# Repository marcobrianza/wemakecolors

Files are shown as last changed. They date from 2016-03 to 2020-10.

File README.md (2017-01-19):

“We Make Colors” is a network of artworks that dynamically generate random colors based on a physical presence near each device.
All copies of the artwork generate and broadcast to each other the new colors in real time using MQTT, current standard protocol for IoT.
The artworks create an unintentional interaction between the spaces and persons. The colors scroll in the device like in a social network timeline: new colors enter from the top and old ones exit from the bottom. All the devices have the same colors at the same time.

The colors of each device are produced by a strip of 9 RGB addressable LEDs.
The new color is generated when the passive infrared sensor interrupts the microprocessor count loop, typically when a human is passing by. There is no identification of the device that generates the new color.
To avoid information flooding and an intentional interaction, the maximum color frequency is one per minute per each device.
The processor is based on the Wi-Fi SoC ESP8266 programmed with the Arduino IDE. The device is open source and can be made with a 60×30 cm laser cutter, available in every Fablab. The main construction element is a 3 mm acrylic sheet. The bill of the material is below 20 €, including a 3 $ donation to Arduino.cc for the IDE support.

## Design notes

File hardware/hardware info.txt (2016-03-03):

board
https://github.com/nodemcu/nodemcu-devkit-v1.0

serial usb drivers
https://www.silabs.com/products/mcu/Pages/USBtoUARTBridgeVCPDrivers.aspx

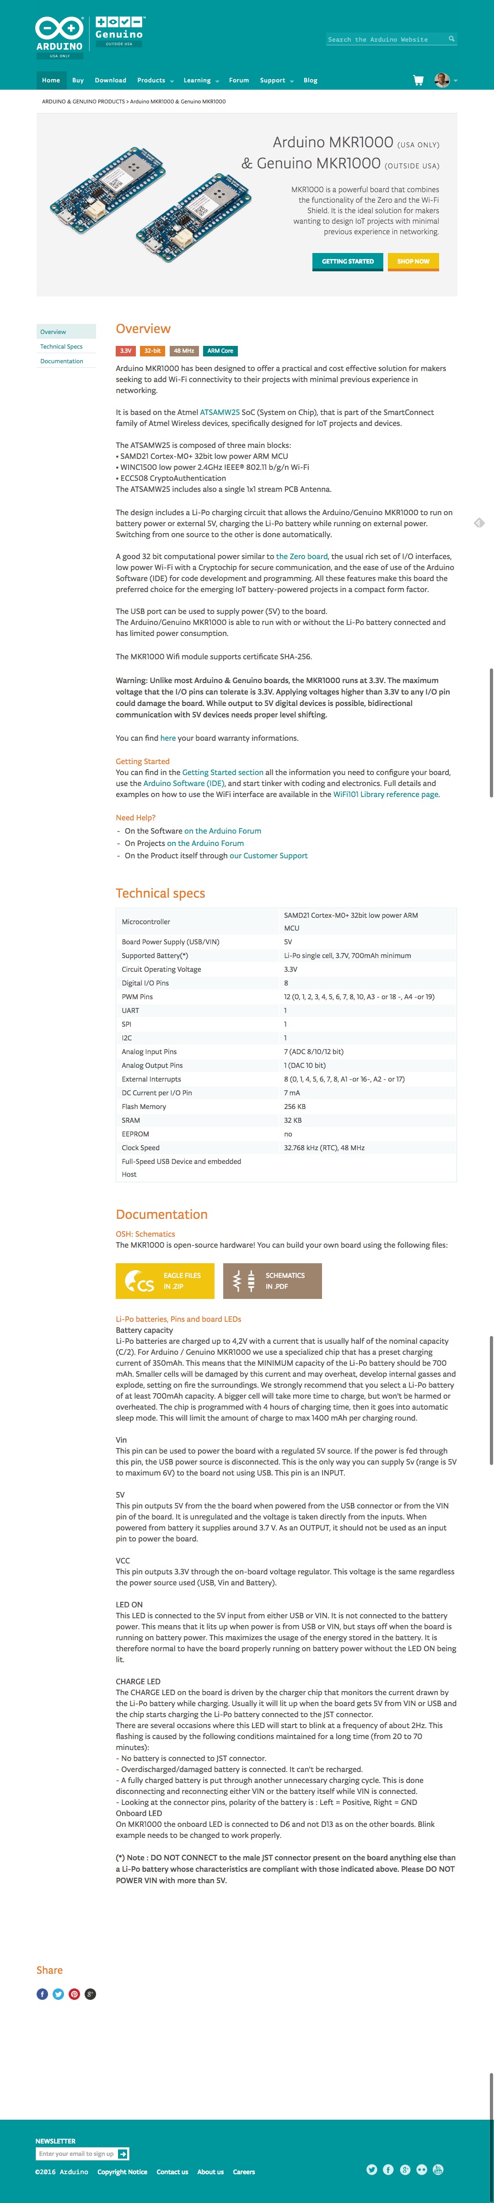
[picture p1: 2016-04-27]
hardware/MKR1000-page.jpg

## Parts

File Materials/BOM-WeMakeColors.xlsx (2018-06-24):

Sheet: bom 1.1
WeMakeColors Bill of materials
 | Product code | Details | Pieces lot | Price lot | Price Piece | Parts | Price parts | Origin | Shipping cost | Price category | Link
Plexiglass white 3mm | WN297 GT | 1050x820 | 6 | 35.63 | 5.938 | 1 | 5.94 | DE | 15 |  | https://www.plexiglas-shop.com/IT/it/xt-allround-8ny276huqre/plexiglas-xt-allround-bianco-wn297-gt-cfy07wjb25z~p.html
Plexiglass white 1mm | 99532 GT | 420x297 | 7 | 8.00 | 1.143 | 1 | 1.14 | DE |  | 7.08 | https://www.plexiglas-shop.com/IT/it/foglio-7amim86q5ps/plexiglas-foglio-bianco-99532-gt-1-0-mm-iqq6a1wurpd~p.html
LED strip 9 LED | White 5 m 30 IP30 | WS2812B | 150 | 16.10 | 0.107 | 9 | 0.97 | CN | 0 |  | http://it.aliexpress.com/item/1m-4m-5m-WS2812B-Smart-led-pixel-strip-Black-White-PCB-30-60-144-leds-m/2036819167.html
ESP8266 | NodeMCU 1.0 |  |  |  | 3.160 | 1 | 3.16 | CN | 0 |  | http://it.aliexpress.com/item/New-Wireless-module-NodeMcu-Lua-WIFI-Internet-of-Things-development-board-based-ESP8266-with-pcb-Antenna/32299982691.html
PIR Sensor | HC-SR501 |  | 5 | 3.88 | 0.776 | 1 | 0.78 | CN | 0 |  | http://it.aliexpress.com/item/Free-Shipping-5PCS-HC-SR501-Adjust-IR-Pyroelectric-Infrared-PIR-module-Motion-Sensor-Detector-Module/1766530570.html
connecting wires | 20 cm |  | 400 | 10.02 | 0.025 | 3 | 0.08 | CN | 0 |  | http://it.aliexpress.com/item/Free-Shipping-400pcs-dupont-cable-jumper-wire-dupont-line-female-to-female-dupont-line-20cm-1P/1727878715.html
connecting wires | 10 cm |  | 40 | 0.64 | 0.016 | 1 | 0.02 | CN | 0 |  | http://it.aliexpress.com/item/40pcs-lot-10cm-2-54mm-1pin-feMale-to-feMale-jumper-wire-Dupont-cable/32226515120.html
USB Cable | White 3m flat |  | 10 | 10.47 | 1.047 | 1 | 1.05 | CN | 0 |  | http://it.aliexpress.com/item/Fedex-shipping-100pcs-lot-3M-Noodle-flat-color-USB-Micro-cable-for-HTC-Samsung-Galaxy-S3/1472726264.html
USB Power supply 1A | a1400 clone |  | 10 | 13 | 1.300 | 1 | 1.30 | CN | 0 | 7.34 | http://it.aliexpress.com/item/10Pcs-lot-Original-Quality-5V-1A-A1400-White-Flat-EU-AC-USB-Wall-Charger-Travel-Adapter/32624571534.html
screw 2x25 | B2X25/BN330 |  |  |  | 0.026 | 10 | 0.26 | PL | 7.9 |  | http://www.tme.eu/it/details/b2x25_bn330/bulloni/bossard/1122886/
screw 2x10 | B2X10/BN341 |  |  |  | 0.013 | 2 | 0.03 | PL |  |  | http://www.tme.eu/it/details/b2x10_bn341/bulloni/bossard/1127799/
screw 2x6 | B2X6/BN341 |  |  |  | 0.019 | 2 | 0.04 | PL |  |  | http://www.tme.eu/it/details/b2x6_bn341/bulloni/bossard/1127772/
spacer 2x15 | TFM-M2X15/DR221 |  |  |  | 0.111 | 2 | 0.22 | PL |  |  | http://www.tme.eu/it/details/tfm-m2x15_dr221/distanziali-in-metallo/dremec/221x15/
bolt 2ma | B2/BN628 |  |  |  | 0.013 | 20 | 0.25 | PL |  | 0.80 | http://www.tme.eu/it/details/b2_bn628/dadi/bossard/m2bn628/
Arduino donation |  |  |  |  | 2.700 | 1 | 2.7 | (NA) |  |  | https://www.arduino.cc/en/Main/Donate
 |  |  |  |  |  | TOTAL € | 17.92 |  |  | 15.22

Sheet: alternatives
WeMake Colors Bill of materials
 | Product code | Details | Pieces lot | Price lot | Price Piece | Parts | Price parts | Origin | Shipping cost | Price cathegory | Link
USB Power supply 1A | AK-CH-03W |  |  |  | 2.2800 | 1 | 2.28 | PL | 7.9 | 2.28 | http://www.tme.eu/it/details/ak-ch-03w/alimentatori-a-presa-di-corrente/akyga/ccabkeyaky-07309/
USB Cable | White 3M flat |  | 10 | 10.47 | 1.0470 | 1 | 1.05 | CN | 0 |  | http://it.aliexpress.com/item/Fedex-shipping-100pcs-lot-3M-Noodle-flat-color-USB-Micro-cable-for-HTC-Samsung-Galaxy-S3/1472726264.html
spacer 2x15 | FIX-TP2-15 | plastic discontinued

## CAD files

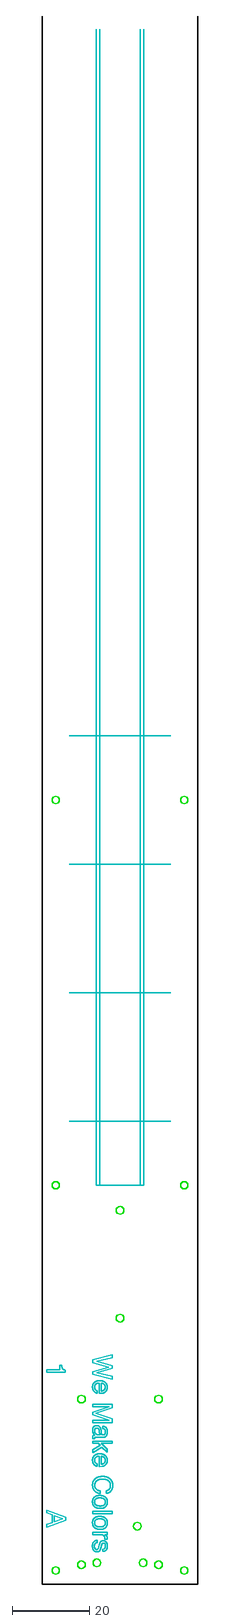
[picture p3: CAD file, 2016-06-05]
design/production/wmc_1A_bottom.dxf
40.3 x 407.0

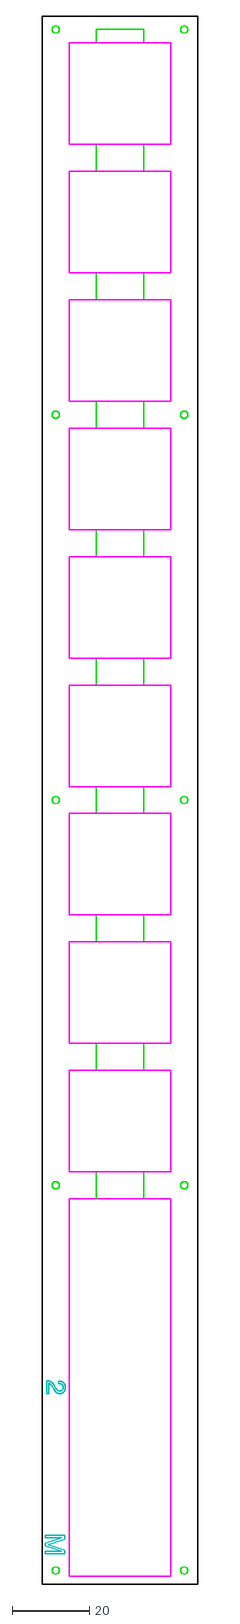
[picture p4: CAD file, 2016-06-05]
design/production/wmc_2M_cuts.dxf
40.3 x 407.0

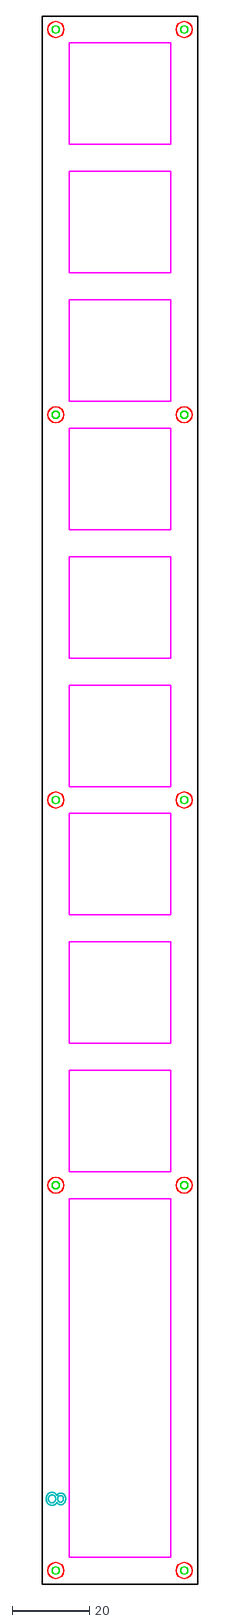
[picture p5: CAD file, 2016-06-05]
design/production/wmc_8_engrave.dxf
40.3 x 407.0

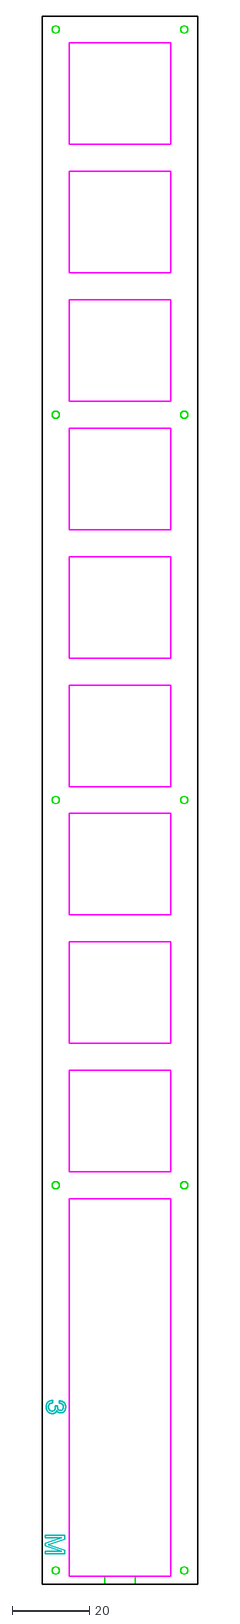
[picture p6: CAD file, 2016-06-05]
design/production/wmc_3M.dxf
40.3 x 407.0

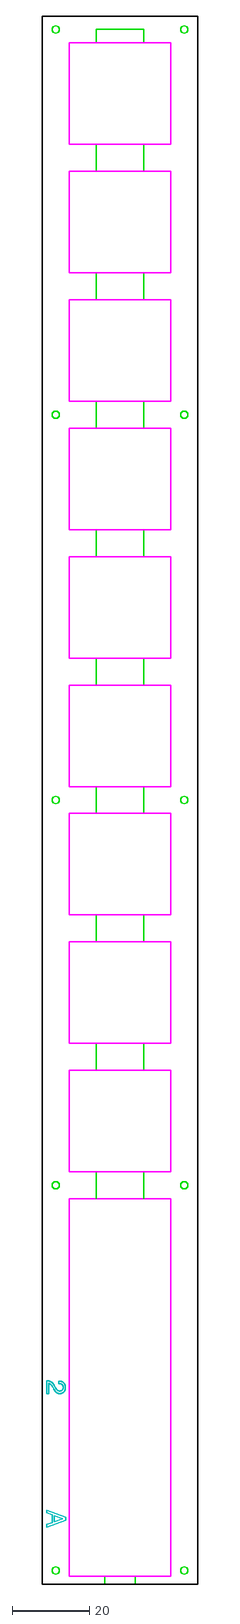
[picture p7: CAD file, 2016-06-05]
design/production/wmc_2A_cuts.dxf
40.3 x 407.0

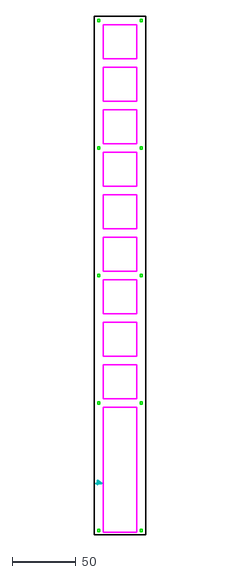
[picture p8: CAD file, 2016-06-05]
design/production/wmc_4.dxf
40.3 x 407.0

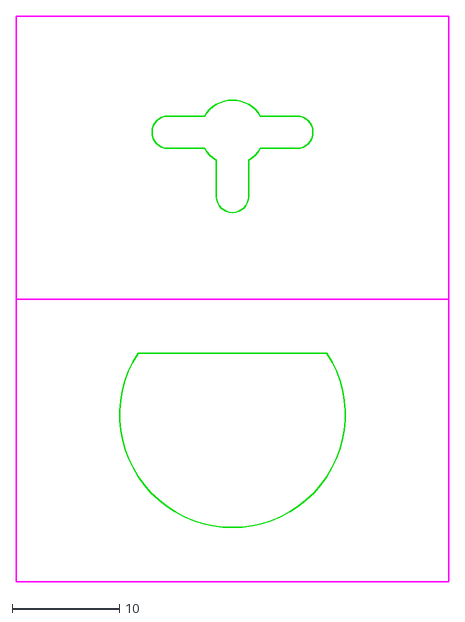
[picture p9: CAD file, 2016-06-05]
design/production/wmc_10_fixing.dxf
40.3 x 52.7

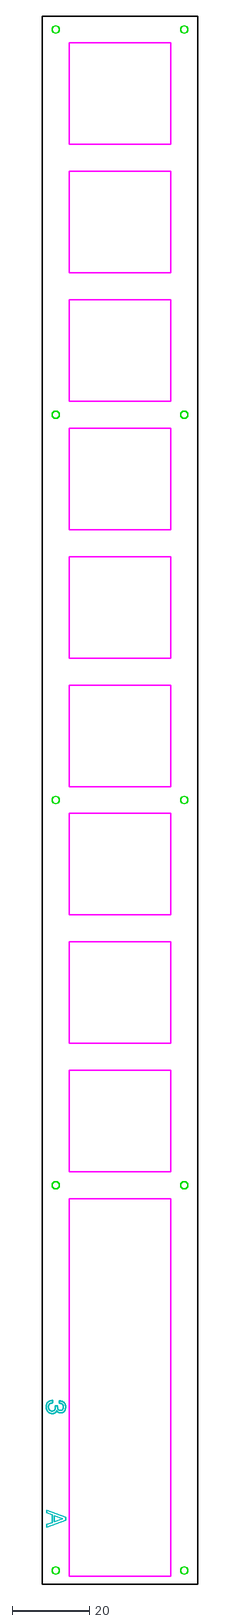
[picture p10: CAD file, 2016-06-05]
design/production/wmc_3A.dxf
40.3 x 407.0

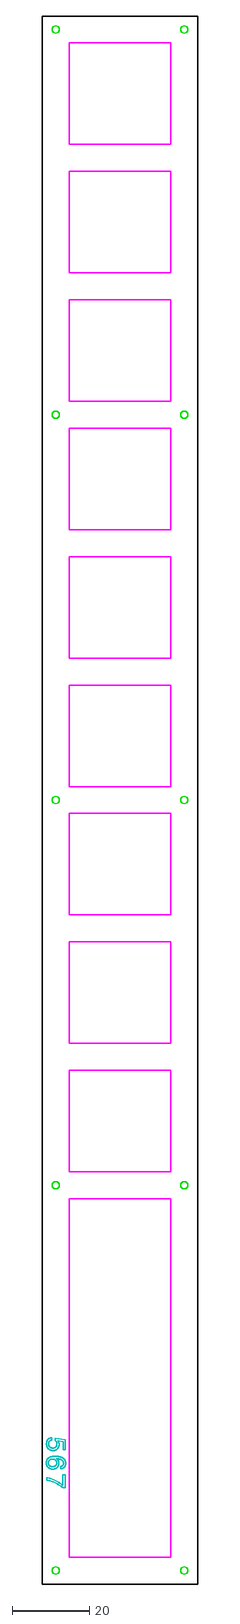
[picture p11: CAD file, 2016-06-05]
design/production/wmc_5-6-7.dxf
40.3 x 407.0

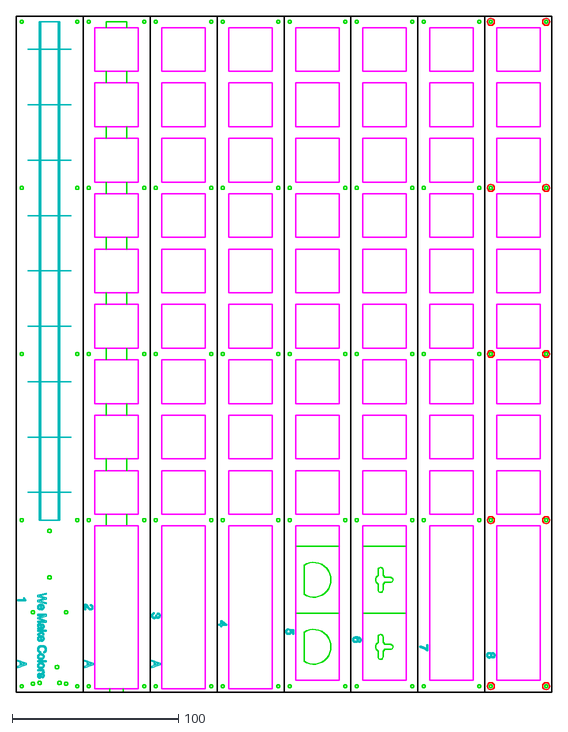
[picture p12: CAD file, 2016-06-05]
design/production/wmc_production_1.1A.dxf
322.6 x 407.0

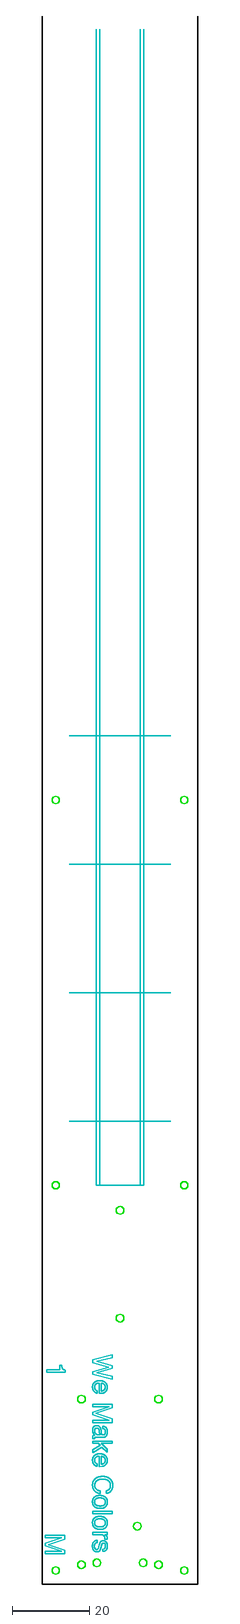
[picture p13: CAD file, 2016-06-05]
design/production/wmc_1M_bottom.dxf
40.3 x 407.0

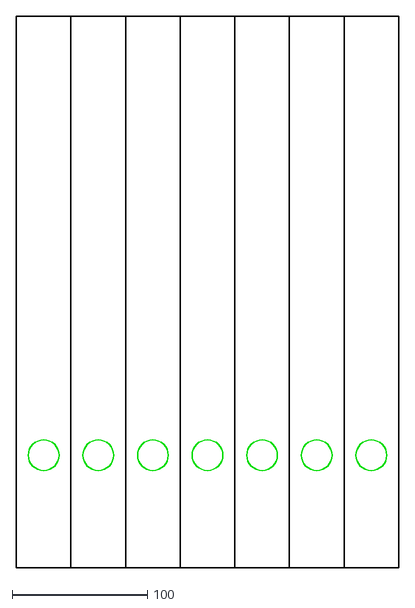
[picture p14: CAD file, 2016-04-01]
design/production/wmc_production_7diffusers.dxf
282.3 x 407.0

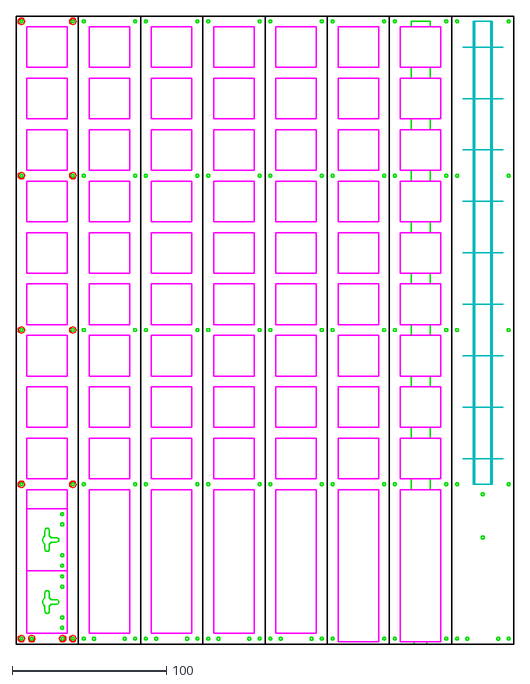
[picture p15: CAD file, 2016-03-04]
design/production/WeMakeColors-production-8.dxf
322.6 x 407.0

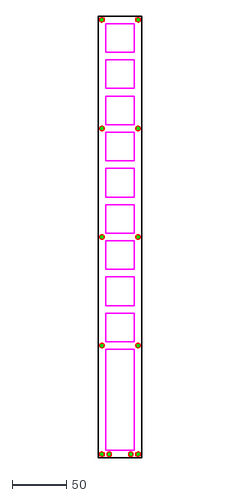
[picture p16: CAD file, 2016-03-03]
design/production/1-engrave.dxf
40.3 x 407.0

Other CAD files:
design/production/wmc_9_diffuser.dxf
design/production/8-bottom.dxf
design/WeMakeColors_1.0.3dm
design/WeMakeColors_1.1.3dm
design/WeMakeColors_production-7diffusers.3dm
design/WeMakeColors_production_1.0.3dm
design/wmc_production_1.1A.3dm

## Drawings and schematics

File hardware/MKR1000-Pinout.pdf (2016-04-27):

# MKR1000 PINOUT

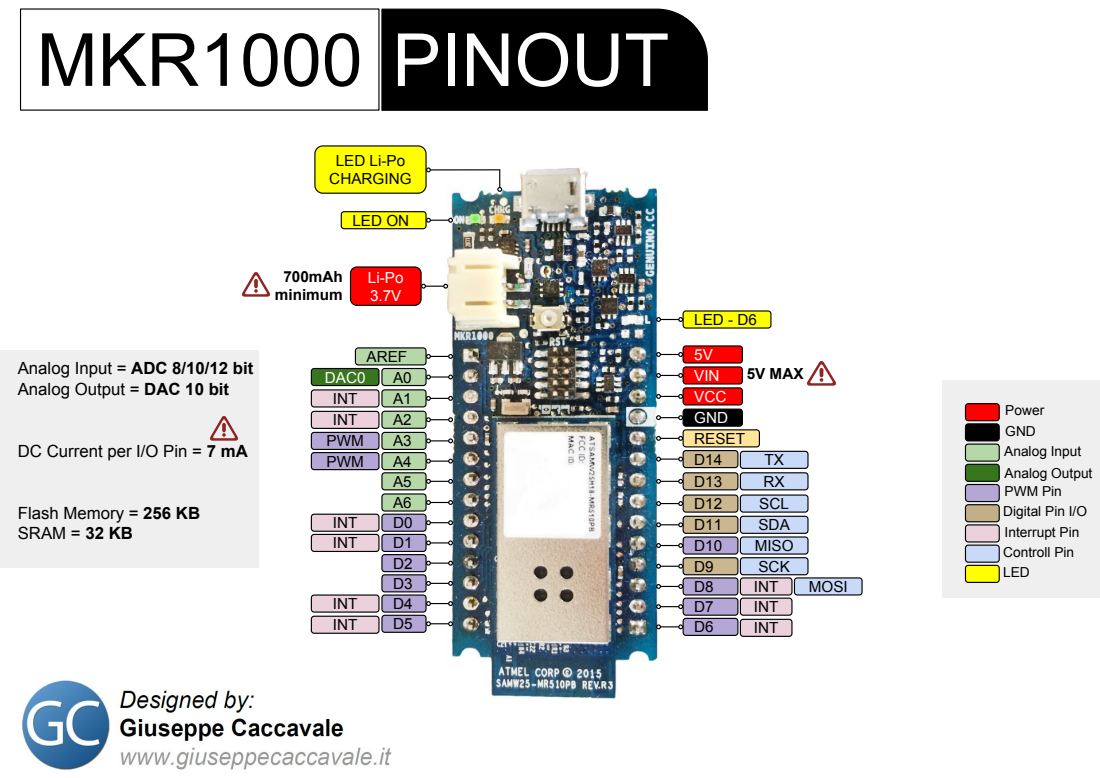
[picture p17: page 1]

Analog Input = ADC 8/10/12 bit
Analog Output = DAC 10 bit

DC Current per I/O Pin = 7 mA

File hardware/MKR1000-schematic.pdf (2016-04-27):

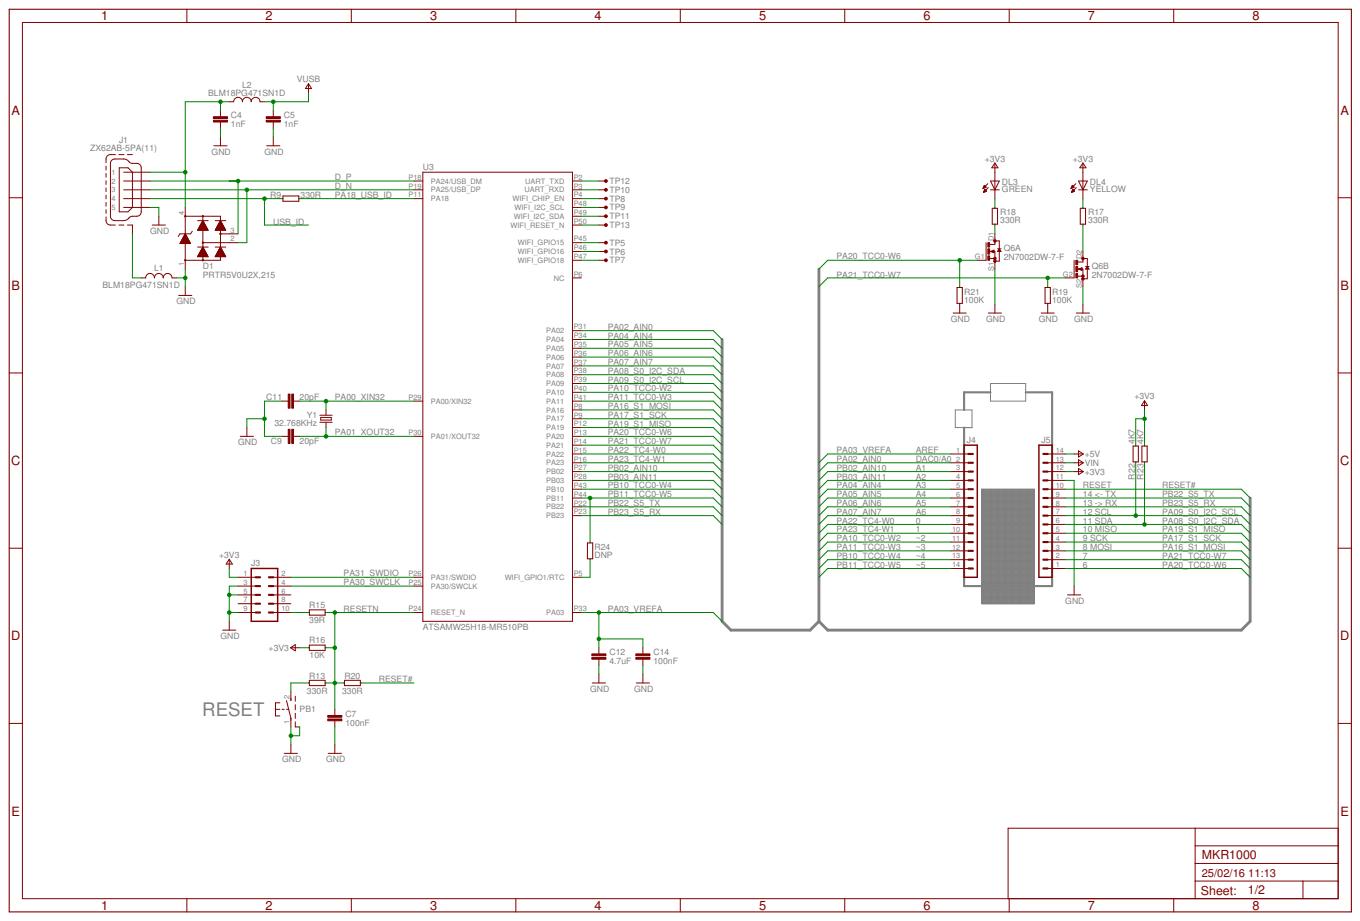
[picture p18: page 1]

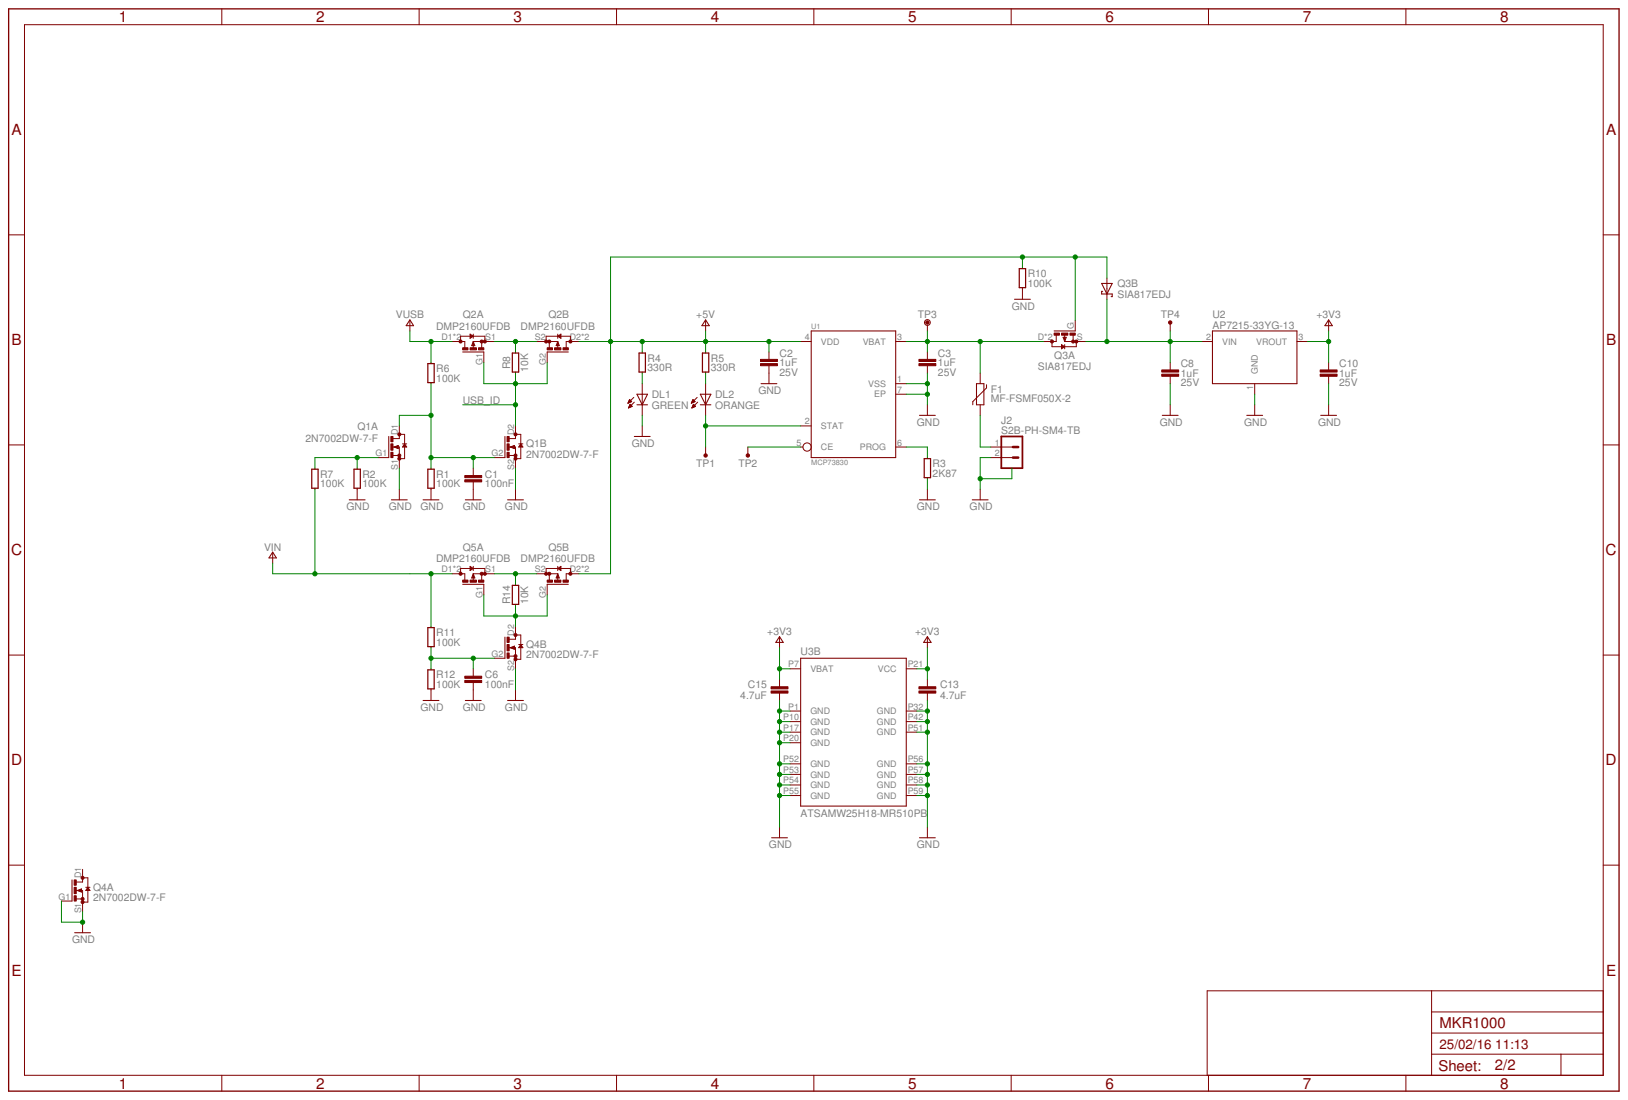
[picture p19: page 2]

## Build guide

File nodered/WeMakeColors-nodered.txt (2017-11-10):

[
    {
        "id": "24e2fff5.8e31e",
        "type": "tab",
        "label": "WeMakeColors"
    },
    {
        "id": "9dfacebf.88269",
        "type": "inject",
        "z": "24e2fff5.8e31e",
        "name": "",
        "topic": "",
        "payload": "true",
        "payloadType": "bool",
        "repeat": "",
        "crontab": "",
        "once": false,
        "x": 122.5,
        "y": 215,
        "wires": [
            [
                "91c1f08a.cf3a4"
            ]
        ]
    },
    {
        "id": "91c1f08a.cf3a4",
        "type": "function",
        "z": "24e2fff5.8e31e",
        "name": "random color",
        "func": "\nvar array = new Uint8Array(3);\n\narray[0] = Math.random() * 15;\narray[1] = Math.random() * 15;\narray[2] = Math.random() * 15;\n\n\nbu=new Buffer(array)\nvar newMsg = { payload: bu };\n\nreturn newMsg;\n",
        "outputs": 1,
        "noerr": 0,
        "x": 319.5,
        "y": 220,
        "wires": [
            [
                "bfa1409d.0ca74"
            ]
        ]
    },
    {
        "id": "bfa1409d.0ca74",
        "type": "mqtt out",
        "z": "24e2fff5.8e31e",
        "name": "",
        "topic": "/WeMakeColors/color",
        "qos": "",
        "retain": "",
        "broker": "7311599b.6bd6b8",
        "x": 564.5,
        "y": 220,
        "wires": []
    },
    {
        "id": "560c032e.b9441c",
        "type": "mqtt in",
        "z": "24e2fff5.8e31e",
        "name": "",
        "topic": "/WeMakeColors/color",
        "qos": "2",
        "broker": "7311599b.6bd6b8",
        "x": 150.5,
        "y": 470,
        "wires": [
            [
                "8875bbff.1bd1c8"
            ]
        ]
    },
    {
        "id": "5ffecd45.d60de4",
        "type": "ui_button",
        "z": "24e2fff5.8e31e",
        "name": "",
        "group": "d0b4d42e.7a7688",
        "order": 0,
        "width": 0,
        "height": 0,
        "passthru": false,
        "label": "Random Color",
        "color": "",
        "bgcolor": "",
        "icon": "",
        "payload": "true",
        "payloadType": "bool",
        "topic": "",
        "x": 119.5,
        "y": 298,
        "wires": [
            [
                "91c1f08a.cf3a4"
            ]
        ]
    },
    {
        "id": "8875bbff.1bd1c8",
        "type": "function",
        "z": "24e2fff5.8e31e",
        "name": "decode color",
        "func": "node.log(\"new message\")\n\nvar array = new Uint8Array(3);\narray=msg.payload;\n\n//var r=msg.payload.buffer[0];\n//var g=msg.payload.buffer[1];\n//var b=msg.payload.buffer[2];\nvar r=array[0];\nvar g=array[1];\nvar b=array[2];\n\nnode.log(r);\nnode.log(g);\nnode.log(b);\n\nmsg.Background=\"#00FF00\";\n\nreturn msg;",
        "outputs": 1,
        "noerr": 0,
        "x": 388.5,
        "y": 470,
        "wires": [
            []
        ]
    },
    {
        "id": "e8f3ede5.8d67",
        "type": "debug",
        "z": "24e2fff5.8e31e",
        "name": "",
        "active": true,
        "console": "false",
        "complete": "payload",
        "x": 450.5,
        "y": 108,
        "wires": []
    },
    {
        "id": "502f2e90.4af54",
        "type": "ui_colour_picker",
        "z": "24e2fff5.8e31e",
        "name": "",
        "label": "",
        "group": "d0b4d42e.7a7688",
        "format": "rgb",
        "outformat": "object",
        "showSwatch": true,
        "showPicker": false,
        "showValue": false,
        "showAlpha": false,
        "showLightness": true,
        "order": 0,
        "width": 0,
        "height": 0,
        "passthru": true,
        "topic": "",
        "x": 123.5,
        "y": 368,
        "wires": [
            [
                "441228de.7ac208"
            ]
        ]
    },
    {
        "id": "441228de.7ac208",
        "type": "function",
        "z": "24e2fff5.8e31e",
        "name": "pick color",
        "func": "\nvar array = new Uint8Array(3);\n\nvar r = msg.payload.r;\nvar g = msg.payload.g;\nvar b = msg.payload.b;\n\narray[0]=r/16;\narray[1]=g/16;\narray[2]=b/16;\n\nnode.log(\"colore\",r,g,b);\n\nbu=new Buffer(array)\nvar newMsg = { payload: bu };\n\nreturn newMsg;",
        "outputs": 1,
        "noerr": 0,
        "x": 345.5,
        "y": 367,
        "wires": [
            [
                "bfa1409d.0ca74"
            ]
        ]
    },
    {
        "id": "12607667.8dd77a",
        "type": "mosca in",
        "z": "24e2fff5.8e31e",
        "mqtt_port": 1883,
        "mqtt_ws_port": 8080,
        "name": "",
        "dburl": "",
        "x": 138,
        "y": 108,
        "wires": [
            [
                "e8f3ede5.8d67"
            ]
        ]
    },
    {
        "id": "7311599b.6bd6b8",
        "type": "mqtt-broker",
        "z": "",
        "broker": "yunshield.local",
        "port": "1883",
        "clientid": "nodino",
        "usetls": false,
        "compatmode": true,
        "keepalive": "60",
        "cleansession": true,
        "willTopic": "",
        "willQos": "0",
        "willPayload": "",
        "birthTopic": "",
        "birthQos": "0",
        "birthPayload": ""
    },
    {
        "id": "d0b4d42e.7a7688",
        "type": "ui_group",
        "z": "",
        "name": "Color",
        "tab": "bb3db2f9.b4222",
        "order": 1,
        "disp": true,
        "width": "6"
    },
    {
        "id": "bb3db2f9.b4222",
        "type": "ui_tab",
        "z": "24e2fff5.8e31e",
        "name": "WeMakeColors",
        "icon": "dashboard",
        "order": 1
    }
]

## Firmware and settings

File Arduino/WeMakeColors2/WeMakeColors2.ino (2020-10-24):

// tested on ESP8266 Core 2.7.4
// https://arduino.esp8266.com/stable/package_esp8266com_index.json
// board NodeMCU 1.0

#include <ESP8266WiFi.h> // built in ESP8266 Core

#include <DNSServer.h> // built in ESP8266 Core
#include <ESP8266WebServer.h> // built in ESP8266 Core
#include <WiFiManager.h>   // version 0.15.0  

#include <ESP8266mDNS.h> // built in ESP8266 Core
#include <ArduinoOTA.h> // built in ESP8266 Core

#include <PubSubClient.h> // version 2.8.0

#define FASTLED_ESP8266_RAW_PIN_ORDER
#include <FastLED.h> // version  3.3.3

#define IN_PIN D2
#define LED_DATA_PIN 5 // D2 is GPIO5
#define CONFIG_PIN 0  // set to GND at startup to force config using builtin button

const char* OTA_PASSWORD = "12345678";

char* THING_ID = "WeMakeColors-11:22:33:44:55:66"; // THING_ID (will be changed automatically on ESP8266)

const char* MQTT_SERVER = "wmc.marcobrianza.it";
const int MQTT_PORT = 1883;
const char* MQTT_TOPIC =   "/WeMakeColors/color";

const byte MSG_LEN = 3;

WiFiClient wifiClient;
PubSubClient mqttClient(wifiClient);

long lastMsg = 0;
byte myColor[MSG_LEN];
int value = 0;

boolean led = LOW;

//LEDs
const int NUM_LEDS = 9;
#define GLOBAL_BRIGHTNESS 255
#define LED_ORDER GRB //GRB=WS2812B  BRG=TM1809

//presence
//#define IN_PIN D2 //defined in core selection
const unsigned int MIN_TIME = 6000; //delay between new color
volatile boolean newPresence = false;

//random color
unsigned long MAX_C = 16; // number of variaitons per each color
unsigned long MAX_CCC = MAX_C * MAX_C * MAX_C;
unsigned long MAX_NUM = MAX_CCC;

unsigned long rnd;
unsigned long countLoops;
byte r, g, b; //locally generated color
byte R, G, B; //color received from remote

CRGB leds[NUM_LEDS];

void ICACHE_RAM_ATTR presence_isr() {
  static unsigned long lastMillis = MIN_TIME + 1; // this initialization enables to generate a new color at startup
  if (abs(millis() - lastMillis) > MIN_TIME) {
    newPresence = true;
    lastMillis = millis();
  }
}

void setup() {
  Serial.begin(115200);
  delay(2000);
  Serial.println("\n WeMakeColors");

  FastLED.setBrightness(GLOBAL_BRIGHTNESS);
  FastLED.addLeds<WS2812B, LED_DATA_PIN, LED_ORDER>(leds, NUM_LEDS);
  memset(leds, 0, NUM_LEDS * 3);
  leds[0] = CRGB(64, 64, 64);
  FastLED.show();

  pinMode(IN_PIN, INPUT);
  pinMode(LED_BUILTIN, OUTPUT);
  pinMode(CONFIG_PIN, INPUT_PULLUP);


  int i = digitalPinToInterrupt(IN_PIN);
  attachInterrupt(i, presence_isr, RISING);

  byte ma[6];
  WiFi.macAddress(ma);

  sprintf(THING_ID, "WeMakeColors-%02X:%02X:%02X:%02X:%02X:%02X", ma[0], ma[1], ma[2], ma[3], ma[4], ma[5]);

  Serial.print("THING_ID: ");
  Serial.println(THING_ID);

  connect_wifi_or_AP(false);

  mqttClient.setServer(MQTT_SERVER, MQTT_PORT);
  mqttClient.setCallback(mqtt_callback);

  setupOTA();
}



void loop() {
  if (!mqttClient.connected())  reconnectMQTT();
  mqttClient.loop();

  countLoops++;

  if (newPresence) {
    newPresence = false;
    Serial.print("sec "); Serial.println(millis() / 1000);
    rnd_color();
    myColor[0] = r;  myColor[1] = g;  myColor[2] = b;
    mqttClient.publish(MQTT_TOPIC, myColor, 3);
  }

  ArduinoOTA.handle();
}

void rnd_color() {
  unsigned long c = countLoops % MAX_NUM;

  r = c    % MAX_C;               // red
  g = c / MAX_C  % MAX_C;         //green
  b = c / MAX_C  / MAX_C % MAX_C; //blue

  Serial.print ("countLoops ");   Serial.println (countLoops / MAX_NUM);
  Serial.print("rgb ");   Serial.print(r); Serial.print(" ");   Serial.print(g); Serial.print(" ");  Serial.println(b);
}





void connect_wifi_or_AP(bool force_config) {
  digitalWrite(LED_BUILTIN, LOW);

  //  WiFi.disconnect();
  //  delay(100);

  WiFiManager wifiManager;
  wifiManager.setDebugOutput(true);
  wifiManager.setAPStaticIPConfig(IPAddress(1, 1, 1, 1), IPAddress(1, 1, 1, 1), IPAddress(255, 255, 255, 0));

  if ((digitalRead(CONFIG_PIN) == LOW) || (force_config == true)) { //config must be done
    wifiManager.setConfigPortalTimeout(0);
    wifiManager.resetSettings(); //reset saved settings
    wifiManager.startConfigPortal(THING_ID);
  } else
  {
    wifiManager.setConfigPortalTimeout(600);
    wifiManager.autoConnect(THING_ID);
  }

  WiFi.mode(WIFI_STA);

  boolean led = false;
  while (WiFi.status() != WL_CONNECTED) {
    delay(500);
    Serial.print(".");
    digitalWrite(LED_BUILTIN, led);
    led = !led;
  }

  //if you get here you have connected to the WiFi
  Serial.print("connected to network ");
  Serial.println(WiFi.SSID());

  digitalWrite(LED_BUILTIN, HIGH);
  leds[0] = CRGB(0, 64, 0);
  FastLED.show();
}


void mqtt_callback(char* topic, byte* payload, unsigned int length) {
  Serial.print("Message arrived [");
  Serial.print(topic);
  Serial.print("] ");
  for (unsigned int i = 0; i < length; i++) {
    Serial.print((byte)payload[i]);
    Serial.print(" ");
  }
  Serial.println();

  if (length == MSG_LEN) {
    R = payload[0];
    G = payload[1];
    B = payload[2];

    for (int i = 0; i < NUM_LEDS - 1; i++) {
      leds[i] = leds[i + 1];
    }
    leds[NUM_LEDS - 1] = CRGB(cal_lut(R), cal_lut(G), cal_lut (B));
    FastLED.show();
  }
}

void reconnectMQTT() {
  // Loop until we're reconnected
  while (!mqttClient.connected()) {
    digitalWrite(LED_BUILTIN, LOW);
    Serial.print("\nAttempting MQTT connection...");
    // Attempt to connect
    wifiClient = WiFiClient(); // workaround to fix reconnection
    if (mqttClient.connect(THING_ID)) {
      digitalWrite(LED_BUILTIN, HIGH);
      Serial.println("connected\n");
      // ... and resubscribe
      mqttClient.subscribe(MQTT_TOPIC);
    } else {
      Serial.print("failed, rc=");
      Serial.print(mqttClient.state());
      Serial.println(" try again in 5 seconds");
      // Wait 5 seconds before retrying
      delay(5000);
    }
  }
}


byte cal_lut(byte c) {
  if (c > 15) c = 15;
  byte lut[16] = {0, 11, 14, 17, 21, 27, 34, 42, 53, 66, 83, 104, 130, 163, 204, 255};
  return lut[c];
}

void setupOTA() {

  ArduinoOTA.setPort(8266); // Port defaults to 8266
  ArduinoOTA.setHostname(THING_ID);   // Hostname defaults to esp8266-[ChipID]
  ArduinoOTA.setPassword((const char *) OTA_PASSWORD);   // No authentication by default

  ArduinoOTA.onStart([]() {
    Serial.println("\nStart OTA");
  });
  ArduinoOTA.onEnd([]() {
    Serial.println("\nEnd OTA");
    delay(100);
  });
  ArduinoOTA.onProgress([](unsigned int progress, unsigned int total) {
    Serial.printf("Progress: %u%%\r", (progress / (total / 100)));
  });
  ArduinoOTA.onError([](ota_error_t error) {
    Serial.printf("Error[%u]: ", error);
    if (error == OTA_AUTH_ERROR) Serial.println("Auth Failed");
    else if (error == OTA_BEGIN_ERROR) Serial.println("Begin Failed");
    else if (error == OTA_CONNECT_ERROR) Serial.println("Connect Failed");
    else if (error == OTA_RECEIVE_ERROR) Serial.println("Receive Failed");
    else if (error == OTA_END_ERROR) Serial.println("End Failed");
  });
  ArduinoOTA.begin();
  Serial.println("OTA Ready");
}

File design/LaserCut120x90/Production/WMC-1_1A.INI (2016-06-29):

[CreateTechnicsCodeMgr]
PrjHasModifyCFG=1
[Technics_Laser_Data]
ModifyTechCFG=0
LayersNumber=5
LayerColor_0=255
LayerColor_1=16776960
LayerColor_2=65280
LayerColor_3=8388863
LayerColor_4=0
ExportRows=1
ExportColumns=1
ExportRowSpace=0.00000
ExportColumnSpace=0.00000
ExportRowCW=0.00000
ExportColumnCW=0.00000
LogicOrgPositionX=803.48000
LogicOrgPositionY=288.68000
LogicOrgPositionZ=-9999999.00000
AtOnceExport=1
IsTwoLaserWorking=0
TableZeroPositionX=0.00000
TableZeroPositionY=0.00000
OutputTimes=1
DelayTime=0
FeedLength=0.00000
FeedSpeed=3.50000
FeedDelayTime=0
MinX=396.52000
MaxX=803.48000
MinY=288.68000
MaxY=611.32000
ChangeSerialNo=0
ArrayMinX=396.52000
ArrayMaxX=803.48000
ArrayMinY=288.68000
ArrayMaxY=611.32000
ClipBoxPower=40.00000
ClipBoxPower2=40.00000
ClipBoxOffsetLen=2.00000
ClipBoxSpeed=25.00000
AlignMachineZPos=0.00000
RouteLength=0.00000
RoutePointNumber=0
OffsetLaserPower=0.00000
OffsetWorkSpeedPer=1.00000
ZHeightForLaserFocus=0.00000
OneWorkNeedTimes=1
TotalWorkTimes=0
[CoordSystem_0]
LogicOrgPosition1=803.48000
LogicOrgPosition2=288.68000
LogicOrgPosition3=-9999999.00000
SPLITBLOCK_NUMBER=0
SPLITBLOCK_NUMBER_0=0.00000
SPLITBLOCK_NUMBER_1=100000.00000
[TechnicsLayers_65280]
TechnicsMode=TECHNICS_LASERCUT
LaserCutConnerPower=90.00000
LaserCutWorkPower=100.00000
LaserCutConnerPower2=10.00000
LaserCutWorkPower2=80.00000
LaserCutFrequency=25000
LaserCutOptimizePathType=1
LaserCutInnerToOuter=1
LaserCutInnerToOuter2=0
LaserCutDownToUpper=0
LaserCutBlockHeight=200.00000
LaserCutAutoSetPathDir=1
LaserCutCicleMinSegNumber=36
LaserCutDisperseLength=0.10000
LaserCutCloseGapLength=0.10000
LaserCutOverlapLength=0.00000
LaserCutAdjustForClose=0
LaserCutQXEnterLength=0.00000
LaserCutDelayMoveTime=0.00000
LaserCutOpenGZDelayTime=0.00000
LaserCutOpenLaserDelayTime=0.00000
LaserCutCloseLaserDelayTime=0.00000
LaserCutDelayTimeAfterCloseLaser=0.00000
LaserCutOneAxisBackLashLength=0.00000
LaserCutTwoAxisBackLashLength=0.00000
LaserCutBackLashAddSpaceLength=8.00000
LaserCutBlowGasType=2
LaserCutAheadBlowGasTimes=0.01000
LaserCutNoCloseGasTimes=0.01000
LaserCutSpeed=12.00000
LaserCutGWAcc=200.00000
LaserCutGWTime=0.01000
LaserCutTrackSize=100
LaserCutLineLength=0.00000
SpaceCutLineLength=0.00000
bSpaceLineFirst=0
LaserCutAdjustMove=0
LaserCutAdjustMoveDelay=0.00000
LaserCutUpLen=0.00000
LaserCutCircleSpeedNum=0
GROUP_ROWS_0=1
GROUP_COLUMNS_0=1
GROUP_ROWSPACE_0=0.00000
GROUP_COLUMNSPACE_0=0.00000
GROUP_ROWCWSPACE_0=0.00000
GROUP_COLUMNCWSPACE_0=0.00000
GROUP_MINX_0=399.06995
GROUP_MAXX_0=803.48000
GROUP_MINY_0=291.22995
GROUP_MAXY_0=608.77005
[TechnicsLayers_8388863]
TechnicsMode=TECHNICS_LASERCUT
LaserCutConnerPower=90.00000
LaserCutWorkPower=100.00000
LaserCutConnerPower2=10.00000
LaserCutWorkPower2=80.00000
LaserCutFrequency=25000
LaserCutOptimizePathType=1
LaserCutInnerToOuter=1
LaserCutInnerToOuter2=0
LaserCutDownToUpper=0
LaserCutBlockHeight=200.00000
LaserCutAutoSetPathDir=1
LaserCutCicleMinSegNumber=36
LaserCutDisperseLength=0.10000
LaserCutCloseGapLength=0.10000
LaserCutOverlapLength=0.00000
LaserCutAdjustForClose=0
LaserCutQXEnterLength=0.00000
LaserCutDelayMoveTime=0.00000
LaserCutOpenGZDelayTime=0.00000
LaserCutOpenLaserDelayTime=0.00000
LaserCutCloseLaserDelayTime=0.00000
LaserCutDelayTimeAfterCloseLaser=0.00000
LaserCutOneAxisBackLashLength=0.00000
LaserCutTwoAxisBackLashLength=0.00000
LaserCutBackLashAddSpaceLength=8.00000
LaserCutBlowGasType=2
LaserCutAheadBlowGasTimes=0.01000
LaserCutNoCloseGasTimes=0.01000
LaserCutSpeed=12.00000
LaserCutGWAcc=200.00000
LaserCutGWTime=0.01000
LaserCutTrackSize=100
LaserCutLineLength=0.00000
SpaceCutLineLength=0.00000
bSpaceLineFirst=0
LaserCutAdjustMove=0
LaserCutAdjustMoveDelay=0.00000
LaserCutUpLen=0.00000
LaserCutCircleSpeedNum=0
GROUP_ROWS_0=1
GROUP_COLUMNS_0=1
GROUP_ROWSPACE_0=0.00000
GROUP_COLUMNSPACE_0=0.00000
GROUP_ROWCWSPACE_0=0.00000
GROUP_COLUMNCWSPACE_0=0.00000
GROUP_MINX_0=403.52000
GROUP_MAXX_0=801.48000
GROUP_MINY_0=336.01000
GROUP_MAXY_0=604.32000
[TechnicsLayers_0]
TechnicsMode=TECHNICS_LASERCUT
LaserCutConnerPower=90.00000
LaserCutWorkPower=100.00000
LaserCutConnerPower2=10.00000
LaserCutWorkPower2=80.00000
LaserCutFrequency=25000
LaserCutOptimizePathType=1
LaserCutInnerToOuter=1
LaserCutInnerToOuter2=0
LaserCutDownToUpper=0
LaserCutBlockHeight=200.00000
LaserCutAutoSetPathDir=1
LaserCutCicleMinSegNumber=36
LaserCutDisperseLength=0.10000
LaserCutCloseGapLength=0.10000
LaserCutOverlapLength=0.00000
LaserCutAdjustForClose=0
LaserCutQXEnterLength=0.00000
LaserCutDelayMoveTime=0.00000
LaserCutOpenGZDelayTime=0.00000
LaserCutOpenLaserDelayTime=0.00000
LaserCutCloseLaserDelayTime=0.00000
LaserCutDelayTimeAfterCloseLaser=0.00000
LaserCutOneAxisBackLashLength=0.00000
LaserCutTwoAxisBackLashLength=0.00000
LaserCutBackLashAddSpaceLength=8.00000
LaserCutBlowGasType=2
LaserCutAheadBlowGasTimes=0.01000
LaserCutNoCloseGasTimes=0.01000
LaserCutSpeed=12.00000
LaserCutGWAcc=200.00000
LaserCutGWTime=0.01000
LaserCutTrackSize=100
LaserCutLineLength=0.00000
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

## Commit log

2016-03-03 Design files
    [0-diffuser.dxf, 1-engrave.dxf, 2-3-4-5-border.dxf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]
2016-03-04 modified laser settings+addesd hanging part in production files
    [WeMakeColors-production-8.3dm, WeMakeColors-production-8.dxf, WeMakeColors-production7.3dm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]
2016-03-06 added BOM
    [BOM-WeMakeColors.xlsx]
2016-03-23 added example of presence detection with interrupt
2016-03-30 lut color calibration and code improvements, python example
2016-04-01 updated design files with new fixing device
    [WeMakeColors-production-7diffusers.3dm, WeMakeColors-production-7diffusers.dxf, WeMakeColors-production-8.3dm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]
2016-04-09 beta release for workshop
    [BOM-WeMakeColors.xlsx, WeMakeColors-production.3dm, WeMakeColors.3dm]
2016-04-09 some fix after workshop
    [test_presence.ino, test_wifi_mqtt.ino]
2016-04-09 adding laser cut production files
2016-04-09 adding a version of FastLED lib that works :-) and final production dxf
    [WeMakeColors-production.dxf]
2016-04-18 Fix latest fasted issue (it was pin naming)
    [test_Blink_BUILTIN.ino, test_LEDs.ino]
2016-04-19 really fix pin name
    [WeMakeColors.ino]
2016-04-27 removed FastLED library since current Master works
2016-05-26 singling connection issues with BUILT_IN LED: blink 500ms=no wifi solid on=no MQTT
    [WeMakeColors.ino]
2016-06-05 new design 1.1 with electronic fixing from bottom, led and buttons accessible, layer numbering, design for MKR1000. optimised BOM.
    [2-3-4-5-border.dxf, 6-ex.dxf, 7-cuts.dxf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]
2016-06-29 added laser cut files for version 1.1A
    [wmc_production_1.1A.3dm]
2016-08-09 1.2 some common fixes
    [WeMakeColors.ino, test_wifi_mqtt.ino]
2016-08-09 Revert "removed support for MKR1000"
    This reverts commit efa3c65484b9ba5e212f87689aab4310d1fe9e67.
    [WeMakeColors.ino]
2017-11-01 Support for FastLED library 3.1.6 and tested con core 2.4.0-rc2
    [BOM-WeMakeColors.xlsx]
2018-01-14 initialise all LEDs with a color, set WiFi OFF
2018-06-24 led to show initial connection try to fix reconnect issue
    [BOM-WeMakeColors.xlsx, WeMakeColors_production-7diffusers.3dm]
2020-03-25 fix for compatibility with core 2.6.3
    [WeMakeColors2.ino]
